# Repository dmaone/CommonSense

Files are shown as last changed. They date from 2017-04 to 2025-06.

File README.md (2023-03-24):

# CURIOSITY REQUIRED TO PROCEED
If you're not curious how this all works and "just want to convert your beamspring" - turn around now.

Nothing but sheer frustration lays on this path for you. This firmware/hardware is not for you, sorry about that.

Find someone how is curious about how things work or walked this path before and entice them to do it for you.

You have been warned.

# This software is provided "as-is".
There's neither a warranty of merchantability, nor warranty of fitness for any purpose.

## No warranties, expressed or implied.
You can fry the chip using this software. If you break it - you own *all* the parts.

If you cannot be relied on to understand written instructions - [here's one with pictures](https://deskthority.net/viewtopic.php?f=7&t=21899), courtesy snackthecat @DT.

If you can't understand it even with pictures - close this page and *never* return. I don't want to be responsible if you electrocute yourself with +5V from USB.

It is not my purpose to "promote adoption" of this software. This is a controller for **my** keyboard. I use it daily, you can use it too if you're smart enough how to do it on your own (but see "no warranties" above) - but that's about it.

If you want to add tap dance macros, or RGB LED support, or "port it to QMK" - by all means, the "Fork" button is right over there. GPLv3 applies, so you MUST make your derivative works available. But please do not ask me to do it, because I explicitly WILL NOT.

There are two exceptions to the above, but you know who you are, because I explicitly promised you.

This is code-only repo, to keep it small. Instructions and pics are moved to [CSI](http://github.com/dmaone/CSI) repo to keep this repo nimble.

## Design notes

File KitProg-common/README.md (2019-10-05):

# KitProg-based converters (currently sun and ADB)

## Flashing 
KitProg is put into bootloader mode by pressing the button while inserting into USB. 

WARNING - pressing the button when it's powered will switch it into CMSIS/DAP mode which you don't want.

Some KitProgs don't respond well to "enter bootloader" command from FlightController. Symptom - rapidly blinking green LED.

If this is the case - press the button on KitProg BEFORE clicking "Update FW" button. If KitProg already runs CommonSense - it will switch to bootloader. If not - see above warning.

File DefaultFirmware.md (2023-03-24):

# DO NOT ASK ANY QUESTIONS ABOUT THIS.

# DO. NOT.

# SERIOUSLY.

# YOU HAVE BEEN WARNED.

If you plan to change anything (and I recommend at least bringing number of rows and columns in sync with your matrix) - skip this section.

**IF** you plan to use vanilla firmware (which will have **8x12** matrix, **default pinout** and will expect **buckling spring** switches) - you can get away with smaller download. You will still need a Windows machine though (see next section for "Windows machine" notes).

* Download [PSoC Programmer](https://www.cypress.com/documentation/software-and-drivers/psoc-programmer-archive) and install it.
* Plug the KitProg side in.
* Open "CommonSense/Capsense.cydsn/Compiled/Capsense.hex".
* IF the "Program" button is grayed out - go to "Utilities", click "Update Firmware". It usually takes ~30 seconds to update. After update, something like "KitProg/xxxxxxxxxxxxxxx" will appear in "Port Selection" window and the button will become blue.
* Click "Program". Takes about a minute to flash.

From now on, you _can_ update firmware using FlightController. Flightcontroller uses .cyacd files, which will be in the same directory as .hex

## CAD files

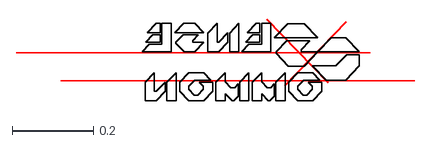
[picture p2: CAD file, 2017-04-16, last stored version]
PCB/commonsense-logo-compact.dxf
0.983 x 0.202

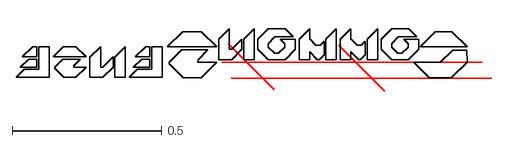
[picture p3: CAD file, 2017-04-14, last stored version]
PCB/commonsense-logo.dxf
1.60 x 0.209

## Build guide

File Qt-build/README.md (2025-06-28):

# hidapi
hidapi 0.9.0+ is required. Luckily, it's available in precompiled form for all 3 platforms in 2020.

## Windows
Download compiled [hidapi package](https://mirror.msys2.org/mingw/mingw32/mingw-w64-i686-hidapi-0.14.0-2-any.pkg.tar.zst) from [msys2 repository](https://packages.msys2.org/package/mingw-w64-i686-hidapi?repo=mingw32), unpack to CommonSense dir (you'll need [7zip-zstd](https://github.com/mcmilk/7-Zip-zstd/releases))
NOTE: There's precompiled DLL in [hidapi repo](https://github.com/libusb/hidapi/releases) - but you'll need libhidapi.a for static linking, DLL won't help.
CAUTION: v0.15.0 is broken, if you can't find 0.14.0-2 - check that [issue](https://github.com/libusb/hidapi/issues/756) is fixed, or you'll have to compile.

If you want to run a debugging build - use dynamic linking and [x86_64 package](https://mirror.msys2.org/mingw/mingw64/mingw-w64-x86_64-hidapi-0.14.0-2-any.pkg.tar.zst) - gdb can't load 32-bit ntdll on Windows 10 :(

NOTE: for qt6 you'll also need x86_64 package, because qt6 no longer supports 32-bit.

## mac
You'll need [brew](https://brew.sh)
Open terminal,
```
/usr/bin/ruby -e "$(curl -fsSL https://raw.githubusercontent.com/Homebrew/install/master/install)"

brew install hidapi
```

## Ubuntu 16.04
```
sudo apt-get install libhidapi-dev libhidapi-hidraw0
```

# Windows build

Because windows app can be a single file - static version is better.
## Building static Qt

*Exclude C:\Qt from antivirus scanning. Source install takes forever if you don't.*

[Official way](https://wiki.qt.io/Building_a_static_Qt_for_Windows_using_MinGW)

### Walkthrough
* Download and run [opensource QT installer](https://www.qt.io/download-qt-installer-oss)
* Select "custom installation"
* On the next page, select "archive" in top box, and then pick version 5.15.2
* Install the following into `c:\qt`
  * `Sources` from the qt 5.15.2
  * from "build tools" - `MinGW 32-bit` for qt5, `MinGW 64-bit` for qt6 (no more 32-bit)
  * `Qt Creator`
  * qt6-only: `Cmake` and `Ninja` from tools
* Fix qt and MinGW versions if needed
* qt6-only
  * install python
  * switch win32 debug mode paths from 32-bit to 64-bit.
* run `build.cmd` (`qt6build.cmd` for qt6)
* https://www.youtube.com/watch?v=bMVbaCiy_XE
* Profit!

Run Qt Creator, Tools->options, select "Build & Run", add new Qt version from `c:\Qt\Static\`
then clone autodetected kit, name it `static`, select newly added Qt version for it.

Don't forget to click "Apply".

Now it's time to open the project. Select `static` kit in setup dialog. In bottom-left corner, select static kit, release config.

Click the green "Run" icon. Find `FlightController.exe` in the build directory - you can copy it and use to control your keyboard.

program crashes, debug run says "During startup program exited with code 0x00000135"? You haven't selected the static kit.

# OS X build
Since OS X application is a folder anyway - no point in making static version. One can use qt from brew.

You'll need XCode. Look at the previous version of this document if the one from appstore doesn't work for you.

The detour section is for people who try to walk this path elsewhere - `mac-build.sh` takes care of this.

## DETOUR
Then you'll have "Error: Could not resolve SDK path for 'macosx' and that would be it.

Because Qt5 requires xcode "because we've got support requests from people using frankenstein buildchains".

```
sudo xcode-select -s /Applications/Xcode.app/Contents/Developer
xcodebuild
```
xcodebuild will require you to accept license. If it complains about no XCode project - you already accepted the license, good!

You have working Qt environment now.

## /DETOUR

From the same path you were before building hidapi (i.e. you should have "hidapi/mac/.libs" accessible from it):
```
git clone https://github.com/dmaone/CommonSense.git
cd CommonSense/Qt-build
./mac-build.sh
```
You should have FlightController.dmg in this dir. Congratulations.

# Linux build
Linux users are supposed to know how to do that :)

Okay, okay. Since there's LOTS of different Linux flavors, let's make it for Ubuntu 16.04. (NOTE: doesn't work for ubuntu 22.04)

```
git clone https://github.com/dmaone/CommonSense.git
cd CommonSense/Qt-build
./ubuntu-build.sh
```
You should have FlightController in current directory.

You must run it from root, because by default HID devices only accessible by root :(
Help with "how to allow working with HID devices from normal user" is gladly accepted.

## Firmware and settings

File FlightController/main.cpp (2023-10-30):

/*
 *
 * Copyright (C) 2016-2023 DMA <dma@ya.ru>
 *
 * This program is free software; you can redistribute it and/or modify
 * it under the terms of the GNU General Public License version 2 as
 * published by the Free Software Foundation.
 */
#include <QApplication>
#include "FlightController.h"

int main(int argc, char *argv[]) {
  QApplication a(argc, argv);
  QCoreApplication::setOrganizationDomain("none.exists");
  QCoreApplication::setOrganizationName("DMA Labs");
  QCoreApplication::setApplicationName("FlightController");
  QCoreApplication::setApplicationVersion("1.0.5.0");
  qInfo() << "Start start!";
  FlightController w{true};
  w.show();

  return a.exec();
}

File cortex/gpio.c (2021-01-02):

/*
 *
 * Copyright (C) 2017 DMA <dma@ya.ru>
 *
 * This program is free software; you can redistribute it and/or modify
 * it under the terms of the GNU General Public License version 2 as
 * published by the Free Software Foundation.
 */

#include "globals.h"
#include <project.h>

#include "gpio.h"
#include "scan.h"

static uint8_t mode;

static uint8_t leds;

static bool solenoid_on;
static uint8_t solenoid_queue;
static uint8_t exp_cooldown;

static int8_t gpio_press_threshold = -2;
static int8_t gpio_release_threshold = 2;

#if NUM_PEDALS > 0
static int8_t gpio_debounce_buffer[NUM_PEDALS];
#endif

#ifdef INVERT_EXPHDR
#define EXPHDR_ON(X) CyPins_ClearPin(X)
#define EXPHDR_OFF(X) CyPins_SetPin(X)
#else
#define EXPHDR_ON(X) CyPins_SetPin(X)
#define EXPHDR_OFF(X) CyPins_ClearPin(X)
#endif

#ifdef INVERT_FIRE
#define FIRE_ON(X) CyPins_ClearPin(X)
#define FIRE_OFF(X) CyPins_SetPin(X)
#else
#define FIRE_ON(X) CyPins_SetPin(X)
#define FIRE_OFF(X) CyPins_ClearPin(X)
#endif

void gpio_reset(void) {
  solenoid_on = false;
  solenoid_queue = 0;
  exp_cooldown = 0;
  EXPHDR_OFF(ExpHdr_0);
  EXPHDR_OFF(ExpHdr_1);
  FIRE_OFF(EXP_ACTUATION_PIN);
  EXPHDR_OFF(ExpHdr_3);
}

void gpio_init(void) {
  mode = config.expMode;
  gpio_reset();
  switch (mode) {
  case EXP_MODE_SOLENOID_NUMCAPS:
    EXPHDR_ON(EXP_SOLENOID_POWER);
    break;
  case EXP_MODE_LEDS:
    break;
  default:
    break;
  }
  // see scan_common_init() in scan_common.c for explanations
  gpio_release_threshold = config.pedalDebouncingTicks + 1;
  gpio_press_threshold = 0 - gpio_release_threshold;

#if NUM_PEDALS > 0
  for (uint8_t i = 0; i < NUM_PEDALS; i++) {
    gpio_debounce_buffer[i] = -1;
  }
#endif

}

void gpio_toggle_expHdr(void) {
  if (mode == EXP_MODE_DISABLED) {
    gpio_init();
  } else {
    mode = EXP_MODE_DISABLED;
    gpio_reset();
  }
}

#define SYNC_LED(MASK, PIN) (leds & MASK) ? EXPHDR_ON(PIN) : EXPHDR_OFF(PIN);

void gpio_setLEDs(uint8_t status) {
  leds = status;
  SYNC_LED(LED_NUMLOCK_MASK, EXP_NUMLOCK_PIN);
  SYNC_LED(LED_CAPSLOCK_MASK, EXP_CAPSLOCK_PIN);
  if (mode == EXP_MODE_LEDS) {
    SYNC_LED(LED_SCRLOCK_MASK, EXP_SCRLOCK_PIN);
  }
}

void gpio_keypress(__attribute__((unused)) uint8_t keycode) {
  solenoid_queue++;
}

static inline void process_solenoid(uint8_t usb_ticks_passed) {
  if (mode == EXP_MODE_DISABLED) {
    return;
  }

  if (exp_cooldown > usb_ticks_passed) {
    exp_cooldown -= usb_ticks_passed;
    return;
  }
  if (solenoid_on) {
    exp_cooldown = config.expParam2;
    FIRE_OFF(EXP_ACTUATION_PIN);
    solenoid_on = false;
  } else if (solenoid_queue > 0) {
    exp_cooldown = config.expParam1;
    FIRE_ON(EXP_ACTUATION_PIN);
    solenoid_on = true;
    solenoid_queue--;
  } else {
    exp_cooldown = 0;
  }
}

#if NUM_PEDALS == 0

static inline void process_pedals() {}

#else

// static uint8_t pedal_state[NUM_PEDALS];

static inline void register_event(uint8_t flags, uint8_t pedal) {
  if (config.pedal_flags[pedal] & PEDAL_EDGE_TRIGGERED) {
    // trigger a press-release
    scan_register_event(0, COMMONSENSE_MATRIX_SIZE + pedal);
    scan_register_event(KEY_UP_MASK, COMMONSENSE_MATRIX_SIZE + pedal);
    return;
  }
  scan_register_event(flags, COMMONSENSE_MATRIX_SIZE + pedal);
}

static inline void debounce_pedal(uint8_t isPressed, uint8_t pedal) {
  int8_t d_buf = gpio_debounce_buffer[pedal];
  bool keyUp = config.pedal_flags[pedal] & PEDAL_NORMALLY_HIGH ? isPressed > 0
                                                               : isPressed == 0;
  // See scan_common.c for details - this is exact copypasta.
  if (keyUp) {
    if (d_buf <= 0) { // Still released. Reset the streak counter.
      d_buf = -1;
    } else { // Was pressed. Bump the streak counter.
      if (++d_buf >= gpio_release_threshold) { // Release the hounds!
        d_buf = -1;
        register_event(KEY_UP_MASK, pedal);
      }
    }
  } else if (d_buf > 0) { // Pressed, no change. Reset the streak counter.
    d_buf = 1;
  } else { // Known pressed, was released. Bump the streak counter.
    if (--d_buf <= gpio_press_threshold) { // Long enough. Press the key.
      d_buf = 1;
        register_event(0, pedal);
    }
  }
  gpio_debounce_buffer[pedal] = d_buf;
}

static inline void process_pedals() {
  uint8_t readout = FSW0_Read();
  for (uint8_t i = 0; i < NUM_PEDALS; ++i) {
    debounce_pedal((readout & (1 << (7 - i))), i);
  }
}
#endif


void gpio_tick(uint8_t usb_ticks_passed) {
  process_solenoid(usb_ticks_passed);
  process_pedals();
}

#undef EXPHDR_ON
#undef EXPHDR_OFF
#undef FIRE_ON
#undef FIRE_OFF

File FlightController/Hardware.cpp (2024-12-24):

#include "Hardware.h"

#include <QDebug>
#include <QPushButton>

namespace {
constexpr size_t kMaxDebouncingTicks{64};
}

Hardware::Hardware(DeviceConfig& config) :
    QFrame{nullptr, Qt::Tool}, config_{config} {
  ui->setupUi(this);
  for (const auto& it: config_.getHostModeNames()) {
    ui->hostModeBox->addItem(it.data());
  }
  for (const auto& it: config_.getExpModeNames()) {
    ui->modeBox->addItem(it.data());
  }
  connect(ui->applyButton, &QPushButton::clicked, this, [this](){ apply_(); });
  connect(ui->revertButton, &QPushButton::clicked, this, [this](){ init(); });
  connect(ui->modeBox, SIGNAL(currentIndexChanged(int)),
          this, SLOT(changeMode_(int)));
}

void Hardware::init() {
  auto config = config_.getHardwareConfig();
  switch (config.adcBits) {
    case 8:
      ui->adcBits->setCurrentIndex(0);
      break;
    case 10:
      ui->adcBits->setCurrentIndex(1);
      break;
    case 12:
      ui->adcBits->setCurrentIndex(2);
      break;
    default:
      qInfo() << "Unknown ADC resolution: " << config.adcBits << "!!!";
  }

  ui->chargeDelay->setValue(config.chargeDelay);
  ui->dischargeDelay->setValue(config.dischargeDelay);
  ui->debouncingTicks->setValue(config.debouncingTicks);
  ui->debouncingTicks->setRange(0, kMaxDebouncingTicks);
  ui->pedalDebouncingTicks->setValue(config.pedalDebouncingTicks);
  ui->pedalDebouncingTicks->setRange(0, kMaxDebouncingTicks);

  ui->adcBits->setEnabled(config_.capabilities.hasTelemetry);
  ui->chargeDelay->setEnabled(config_.capabilities.hasChargeSequencer);
  ui->dischargeDelay->setEnabled(config_.capabilities.hasChargeSequencer);

  ui->modeBox->setCurrentIndex(config.expHdrMode);
  ui->Param1->setValue(config.expHdrParam1);
  ui->Param2->setValue(config.expHdrParam2);

  ui->hostModeBox->setCurrentIndex(config.hostMode);
}

void Hardware::updateParamVisibility_() {
  // Nothing - both modes blink something on keypress now.
}

void Hardware::changeMode_(int idx) {
  Q_UNUSED(idx);
  updateParamVisibility_();
}

void Hardware::apply_() {
  std::vector<uint8_t> adcBitMap {8, 10, 12};
  HardwareConfig config;
  config.adcBits = adcBitMap[ui->adcBits->currentIndex()];
  config.chargeDelay = ui->chargeDelay->value();
  config.dischargeDelay = ui->dischargeDelay->value();
  config.debouncingTicks = ui->debouncingTicks->value();
  config.pedalDebouncingTicks = ui->pedalDebouncingTicks->value();
  config.expHdrMode = ui->modeBox->currentIndex();
  config.expHdrParam1 = ui->Param1->value();
  config.expHdrParam2 = ui->Param2->value();
  config.hostMode = ui->hostModeBox->currentIndex();
  config_.setHardwareConfig(config);
}

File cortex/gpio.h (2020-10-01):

/*
 *
 * Copyright (C) 2017 DMA <dma@ya.ru>
 *
 * This program is free software; you can redistribute it and/or modify
 * it under the terms of the GNU General Public License version 2 as
 * published by the Free Software Foundation.
 */

#pragma once
#include <stdint.h>

#define LED_NUMLOCK_MASK 0x01
#define LED_CAPSLOCK_MASK 0x02
#define LED_SCRLOCK_MASK 0x04

#define EXP_CAPSLOCK_PIN ExpHdr_3
#define EXP_NUMLOCK_PIN ExpHdr_1
#define EXP_SCRLOCK_PIN ExpHdr_0

// Comes on briefly when a key is pressed
#define EXP_ACTUATION_PIN ExpHdr_2

// Provides solenoid enable signal, for xwhatsit solenoid board compatibility.
#define EXP_SOLENOID_POWER ExpHdr_0

void gpio_init(void);
void gpio_toggle_expHdr(void);
void gpio_tick(uint8_t tick);
void gpio_setLEDs(uint8_t status);
void gpio_keypress(uint8_t keycode);

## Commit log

2016-05-29 Squashed 'tmk_core/' content from commit 836e209
    git-subtree-dir: tmk_core
    git-subtree-split: 836e209fdfc4b49215159294dda0d042d0f81984
    [BoardDeviceMap.cfg, BootloaderDeviceMap.cfg, master.cfg]
2016-06-04 Flight controller acquires new functionality. Also prototype of the C2(command and control) framework.
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2016-06-05 Remove unneeded stuff from bootloader
    Bootloader was too smart and required pressing a button to actually start.
    Removed that - now it starts always.
    This is not a problem actually - if there's a valid application, it starts
    [main.c]
2016-06-05 Niceties - statuses, die temp..
    Procrastinating before reworking the USB/doing EEPROM config storage.
    Testing matrix - looks like parasitic capacities _do_ play some role.
    Lowered the threshold - need to make it tuneable.
    [main.c]
2016-06-10 Enhance ADC readout dashboard
    Switch to 10 bit ADC resolution
    Return number of actual columns in ADC readout reports
2016-06-10 Towards proper handling of row/col mappings
    Disable setup tab if no device
    Dynamically resize matrix monitor and row/col mappers
    Row/col numbers to assist in mapping
2016-06-13 Layout editor
    Import layout from file
    Apply layout to device config
    Revert layout to device config
    NVRAM-reladed bugfixes and enhancements
    TODO: Layout editor keypress highlighting
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2016-06-18 Bring the device out of endless reset loop on power-up.
2016-06-19 Interlaced scan, new console HID report
    1 mS control channel message frequency
    Lots of pretty high-voltage ringing
    Need to investigate
2016-06-20 Something resembling a keyboard! (but bouncy as hell)
    Clean up unneeded parts of tmk_core includes
    62KRO HID report
    Add configurable threshold stored in EEPROM
    4x oversampling in attempt to defeat voltage spikes
2016-06-30 Fix sensor hanging in untied position
    [main.c]
2016-07-05 Fighting for microseconds
    Grounding pins in hardware to allow more time to settle the sense lines.
    Driving rows instead of columns - seems working but crosstalk is downright
    crazy.
    Will not probably work for beamspring - though I don't have one to test.
2016-10-16 Upgrade to PSoC Creator 4, new scope and results.
    Runtime pin drive mode change -> ability to reverse-drive F122.
    Needs tweaking.
    [main.c]
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2016-12-17 Non-interlaced version, 2.9kHz scan rate
    Made analog part simpler - should make pin selection really easy.
    One should no longer be constrained by availability of EN lines
    in a port.
    [main.c]
2017-02-05 switch to 16 bit reporting and diff ADC.
    TQFP-100 5667 chip is now the platform
    [controller.kicad_pcb, controller.sch]
2017-02-05 Keyboard configuration files.
    [f122.cfg]
2017-02-28 CKIT COMPAT. BROKEN External dependencies removed
    ADC reference is now VDDA
    Chip is for prototype controller board.
    [BoardDeviceMap.cfg, BootloaderDeviceMap.cfg, master.cfg]
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2017-03-03 100kHz 1-row 2-column mode for !!SCIENCE!!
    Pretty pictures resulting from.
    Actual interrupt handler for the interrupt mode - forgot to include
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2017-03-20 Moving to QtMessages for logging.
    It compiles and works on a single case!
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2017-03-21 Assembling config back, matrix monitor
    Foundation for noise floor editor.
    [DeviceConfig.cpp]
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2017-03-22 noiseFloor is now deadband, threshold editor WIP
    [DeviceConfig.cpp]
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2017-03-25 First swing at power saving
    Added 1ms period timer for system timer.
    Systick is not used because more code.
    Putting system into AltActive when it's not busy to save some power.
    There's not much of that:
    36MHz: 28/23mA
    48MHz: 34/25mA
    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
2017-04-01 Analog path optimizations
    Use discharge and extref pins from the same side ADC is on.
2017-04-02 Prepare for descent^Wsuspend. And cleanups
    HWState register doesn't make sense with ints - removed.
    USB suspend watchdog moved to hardware with priority 0 int.
    Waiting for USB buffers aborts on suspend now.
    Scancode-related constants replaced with defines - as it should be.
    SysTimer switched to UDB implementation to avoid sync logic with other
    parts of the system (USB suspend watchdog, namely).
    System power states added and implemented "in theory that's how it should
    work". Compiles, works at full power. Checkpoint for debugging.
    [main.c]
2017-04-03 Rip "warmup" state - detect bus state instead
    Move power-related stuff to USB_PSoC.c
2017-04-03 Ugly unrolled version, scan fixes. 3.35kHz
    Fix: out-of-band value no longer shifts data (was not updating pointers
    to ADC buffer if out of band or skipped key).
    pre-calculating matrix pointers to make things a bit faster.
    ISR with no function calls as recommended by The Book - need to roll
    back to inline function, readability suffers too much
2017-04-04 RWU works. Waking up with RWU disabled doesn't
    [main.c]
2017-04-05 Intermediary DMA buffer for results storage. 6.2kHz
    USB interrupts given priority over scanning to avoid missing USB
    control traffic.
2017-04-06 48/12MHz, 30/14mA, 5.3kHz
    Fix: interrupts disabled on suspend
    Nicer pin debug.
    [main.c]
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2017-04-10 F122 mode - pin mapping fixes, code readability.
2017-04-11 Fix: close files you open!
    [DeviceConfig.cpp]
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2017-04-12 Matrix readouts and scope shots.
    [f122-no1-pressed.csv, f122-no1-resting.csv, f122-no2-capless.csv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]
2017-04-12 PCB design experiments.
    [f122-no1-no-cover.csv, foil tests.xlsx, no1-1-key-pressed.csv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]
2017-04-14 KiCad is a failure. Remove files.
    [controller.kicad_pcb, controller.sch]
2017-04-14 Prototype PCB
    [commonsense-logo.dxf]
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2017-04-16 0.05", 0.1" and 0.156" PCB versions
    [BoardOutline.gbr, Bottom.gbr, BottomAssy.gbr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]
2017-04-18 Delay bank editor and keyboard speed throttle in delay 0
    Also readability.
2017-04-19 Key release doesn't set cooldown timer now.
2017-04-28 CommonSense MF PCB - semi-final
    [BoardOutline.gbr, Bottom.gbr, BottomAssy.gbr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]
2017-05-09 building instructions updated, cleaner build
    [5251.cfg, F122.cfg]
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2017-05-12 CS-MF PCB, TQFP version
    [BoardOutline.gbr, Bottom.gbr, BottomAssy.gbr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]
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2017-09-02 Project MF TQFP-based PCB
    [BoardOutline.gbr, Bottom.gbr, BottomAssy.gbr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]
2017-09-24 Fixing CS-MF defects
    [Bottom.gbr, BottomMask.gbr, Through.drl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]
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2017-11-12 Fixed highlight in matrix monitor for buckling spring version
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2018-01-02 Scanner sanity checker
    Disables spam if detects spurious activity after sensor activation
2018-01-13 blinkenlights! Also TX queue to prevent overwhelming of the device's RX buffers.
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2018-02-04 Remove extra include dirs, fix compilation
    [main.c]
2018-03-25 Missing files from 4.2 migration
    Also ILO trimmer and systimer UDB usage optimization
    [main.c]
2018-04-15 A wild BLE appears!
    Warning! Extremely clowny-system-design.
    Doesn't work when not plugged into USB, for example - because tries to
    output BOTH to USB and BLE.
    Do not use anywhere near any environment!
    [BLE.sdf]
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2018-04-15 i2c anti-stall
    [BLE.sdf]
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2018-05-06 A wild KitProg ADB converter appears!
    [AEKII-config.cfg]
2018-05-06 Sun Type 5c KitProg converter
    [AEKII-config.cfg, SunType5c.cfg]
2018-05-10 Fix for sticking mods in ADB mode, multiple device
    awareness, not yet support! :)
2018-05-10 Multiple devices selection support.
    Please don't have several keyboards in bootloader mode at once. It will
    work, but it would be hard to discern which one is which, and
    consequences are dire!
2018-06-09 thresholds up to 255, "Reconnect" button, small fixes
    [DeviceConfig.cpp]
2018-06-09 CSSK custom controller
    [cssk.cfg]
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2018-07-28 Sangdrax-inspired fixes to FlightController
    Prevent config operations while matrix monitor is running
    Rename menu items for clarity
    [DeviceConfig.cpp]
2018-08-03 default 8x24 matrix, better default pinout.
    [xtant.cfg]
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2018-09-09 fix: go low power on USB suspend.
    This will still violate USB spec as it will draw 100mA - but I'm too
    lazy for that now (I'm short on pins and proto PCB doesn't have SUSP
    routed)
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2019-07-20 Order macros, add macro editor docs
    Turns out I forgot how to use Macro editor.
    So new user has no chance to figure out how to add a new macro
    when there are existing ones, and will instead edit one they already have.
    Also, since upcoming new macro engine must have tap macros first - keeping
    the macro vector sorted. Sorting essentially applies on config upload - so
    things will change order on config reload/device reconnect - but it's not
    that big of a problem.
2019-07-20 Fixing layer switching
    LLck keys were just directly setting the layer, which is not the idea.
    The idea is that LLck are same as Fn, only you don't need to hold them.
    Plus comments and debugs.
2019-07-20 Battery-powered and multi-chip related changes
    Both are part of BLE experiments. EXTIF is I2C link to BLE module,
    SELF_POWERED is self-explanatory.
    Plus stuff I don't really remember why.
    WARNING - not sure it will even compile.
2019-07-24 Documentation update.
    Making abundantly clear that I'm not obligated to help people who don't want to do the legwork required.
    Also unifying the LED config with xwhatsit - but literally nobody uses that config, so I can do it with impunity.
2019-07-27 Change progress indicators from dots to number
    Works better with config upload/download - shows which block you got stuck on.
    [DeviceConfig.cpp]
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2019-07-29 Turn off setup mode after FlightController goes away
    It is impossible for firmware to figure out on it's own if FlightController
    connected or not. So FC sent a command at exit to turn setup mode off.
    Guess how reliable that was (actually, it was mostly working).
    For some time now, FC polls the device for status ~3 times per second.
    So we can have an idle timeout (set to 2000 ticks(=milliseconds) now) after
    which we can consider FlightController gone.
    Firmware will not restart on that timeout - so if FC crashes, you won't lose
    your uncommitted changes. It should restart scan module - to prevent spam
    in case said configuration is not sane. But apply_config() seems to crash
    the firmware someh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
2019-07-29 Latency indicator and adaptive polling
    I thought I saw some latency problems on some firmware build.
    Turns out it wasn't the case (actual reason was command didn't return
    any USB messages and that for some reason froze later hid_write()'s).
    But the indicator is there, so it will stay.
    Also noticed that FC uses WHOLE CORE ALL THE TIME.
    So, poll rate is now adaptive - it goes to slow mode after 500 empty polls.
    Goes back to fast mode if FC tries to send anything to firmware, too.
2019-07-29 Put device accesses under the mutex
    It's not that they're called concurrently - this was part of figurint all
    that "why hid_write() freezes" saga. But well, it's better to lock
    non-threadsafe things.
2019-08-09 Updated the docs.
    [f122.cfg, xtant.cfg]
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2019-10-05 Unify scanner module interface, split KitProg-based converters by dirs
    Separate .h is not needed. Never was.
    KitProg-based converters now have a separate dir each, for ease of use.
    Plus FlightController update to display switch type in status bar and make better device selection dialog most of you will never see.
    [AEKII-config.cfg, SunType5c.cfg]
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2019-11-11 Make main window a bit larger
    switch name doesn't fit otherwise.
    New size is 780x550, which should be enough for everyone.
2019-11-11 Gray out unsupported options
    Some scanners are more equal than others. MagValve doesn't have ADC (though has delays), ADB/Sun converters don't even have thresholds.
    [DeviceConfig.cpp, Hardware.cpp]
2019-11-11 "dma_core" -> "cortex".
    Because "dma_core" ees a stoopid name. I just needed something that's not "tmk_core" at the time.
    And cortex is the part of a brain that does zee thinking (most CommonSense varieties also have "reflexes" part, which are part of the particular project)
    I considered "core" - but "core/core.h" is a bit too much.
    [main.c]
2019-12-15 Microswitch scanner support
    Completely untested (Firmware starts up, but that's as far as I can test). Should work, but..
    Incremented version of FC because new type of switch is added, but 1.0.0.4 will work, just say that it doesn't know about switch type.
    Good luck!
    [DeviceConfig.cpp, main.c, main.cpp]
2020-01-10 Fixed row drive modes for 8x24 project.
    For some unknown reason they were in "Strong drive, slow" (instead of
    "resistive pullup/pulldown"), likely causing sense stability because
    hell of a ringing.
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2020-02-16 Ignore empty layout positions
    Previously those were resolved into random scancode because of uint for cycle counter.
    That is fixed, and a guard is added to ignore matrix positions not resolving into anything.
    Also some good ole debug prints.
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2020-02-17 Ensure "all keys up" is generated
    It was up to a specific scanner module implementation to generate "all keys up".
    This led to higher-layer keys stuck sometimes on MagValve.
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2020-04-13 mv 8x16.cydsn alt-wiring-8x16.cydsn to avoid confusion
    the 8x16 uses legacy pinout and should not be used for the new projects.
    [main.c]
2020-07-18 Fix crash on unknown switch type
    [DeviceConfig.cpp]
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2020-07-18 Bootloader key - send keyboard to bootloader by pressing a key
    Inability to send keyboard into bootloader from host being
    "security feature" is total and utter bullshit, because when adversary has
    the capability to reflash your keyboard remotely - it's much easier to
    install keylogger at OS level, without risking discovery should reflash go
    wrong and brick the device.
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2020-08-21 Removed large binaries from the repo
    [BoardOutline.gbr, Bottom.gbr, BottomAssy.gbr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]
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2020-09-15 pointless refactor
    Bringing everything to same naming scheme, trying to avoid DeviceInterface singleton
    [DeviceConfig.cpp]
2020-09-15 Fix SIGSEGV in Hardware dtor
    [Hardware.cpp]
2020-09-15 Reset device to specific status on connect
2020-09-15 Final replace of _x to x_, cleanups of unused vars
    [DeviceConfig.cpp]
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2020-10-01 Gated("Logic Scan", 1001SD4xxS) Honeywell Microswitch support
    The switches are "If OE pulled down, pulls down output pin if pressed".
    Levels are inverted by FPGA, software sees "pull row up, read which columns are up now" - like, normal contact switches.
    [DeviceConfig.cpp, main.c]
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2020-10-01 Uncomment USB suspend functions on USB suspend path.
    Looks like suspend magic just didn't work for a couple yearas..
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2021-08-23 RedragoN/Kumara K552N keyboard
    Got tired of using both hands to change volume - swapped the controller.
    Let it serve an example that you can use CS with contact switches (as
    long as you have diodes)
    [main.c]
2021-08-23 Update Sun KitProg converter config, move AEKII config to proper place.
    [AEKII-config.cfg, SunType5c.cfg]
2023-02-01 Optimize out the magic PSoC component
    PSoC6 ADC didn't work too well with SAR_ADC verilog-based component.
    This replaces it with a count7 + some small logic, optimizing resource usage a bit along the way: 6 macrocells, 8 P-terms, 2 status and 1 control registers.
    Also this uncovered an issue where FPGA compiler *sometimes* compiles `or -> or -> not` into a 60us delay between second and third stages. That logic controlled unattended start of the scan cycle, and since it had to go, firmware must explicitly start the scan cycle now. The upside is further 7 macrocells, 6 P-terms and a control register (despite adding a control register for the firmware control!)
2023-03-02 Write PSoC5 EEPROM in blocks
    Previously I was using a VERY SLOW byte-write API having a 16x write
    multiplication factor.
    Not too much of a deal with 1M rewrite rate, but still.
    [settings.c]
2023-03-23 FW 2.0: more packet-effective telemetry, HID IDLE support
    * Telemetry now transmits max. number of keys that fits the packet, not one row.
    * Firmware is 2.0 due to telemetry format change.
    * Actually detect boot mode and properly generate rollover state.
    * HID idle timer support - keyboard must retransmit state periodically (in addition to sending on update).
    * Reduce telemetry rate - new code overwhelms USB module capability causing controller reset after couple seconds of telemetry streaming.
    * Improve reliability of FlightController disconnect detection.
2023-03-24 Housekeeping: remove HPWR, merge capsense projects.
    Basically, capsense projects were all same hardware, but a bit different config.h and pinouts.
    Since all the custom variations are now in my physical posession, I chose to resolder everything to One Canonical Layout and make config.h tunable.
    Also, since there's ECN for upping initial power budget to 500mA, HPWR pin no longer needed and was removed.
    [main.c]
2023-03-25 Fix SysTimer interrupt to be RAISING_EDGE
    For some strange reason it changed to LEVEL by itself, causing SysTimer
    to be ~10x faster than it should be.
    Added systime to status packet, as well as current systime and time drift
    indication, plus controller reset detection and logging
    Also auto-reset thresholds when backfilled from telemetry (previously
    had to press "Revert").
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2023-08-19 Firmware 2.1, FlightController 1.0.4.0: PS/2 protocol support
    KitProg-PS2.cydsn converts a KitProg to a USB-{XT/AT/PS/2} converter.
    Load misc/PS2.cfg from file and upload to controller to avoid manual
    configuration.
    Currently supports scancode set 2. Can be remapped using layout - but if
    keyboard sends same scancode for two keys - bad luck, those cannot be
    disambiguated.
    [PS2.cfg]
2023-08-19 Cleanup
    * remove debug wires from Kitprog-PS2
    * fix TimerIRQ incorrectly being LEVEL in several projects
    * re-save .cyprj with newer PSoC creator version to avoid later
    unrelated changes.
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2023-10-30 FC 1.0.5.0, CS 2.2: config.hostMode
    ARM mac's HID is SO HORRIBLY SLOW, special mode needs to be introduced
    to handle that.
    ..and since we have that mode - why not swap ALT/GUI so there's no need
    to touch layout when switching between win and mac host modes.
    [DeviceConfig.cpp, Hardware.cpp, main.cpp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]
2023-10-30 Fix MacOS compile error
    [DeviceConfig.cpp]
2024-12-24 fix hostMode not saving, poll status again
    [Hardware.cpp]
2025-06-28 QoL fixes
    * no longer considering "keyboard went insane" a permanent condition. If
    it can live for 1 second without spamming keys, it's working. Also
    spamming is now 5 keys, not 3, to allow ctrl-alt-del to pass.
    * Since we're supposed to be polled by FC 5 times a second - get out of
    setup mode after 1 second of inactivity.
    * pollTimer renamed mainTimer in FC - because there's now another poll
    timer - for status polling
    * DRY killing timer
    * updated qt build instructions
